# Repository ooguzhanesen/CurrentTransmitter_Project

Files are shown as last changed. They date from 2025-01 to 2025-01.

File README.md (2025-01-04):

# CURRENT TRANSMITTER KARTI
## KART ÖZELLİKLERİ
- 3 ADET  4-20 mA analog çıkış
- STM32f103C8 mikrodenetleyici 
- RS485 Portu
- 7-28 volt güç girişi
- Aşırı votaj koruması
- Ters bağlantı koruması
- Akım limitleyici
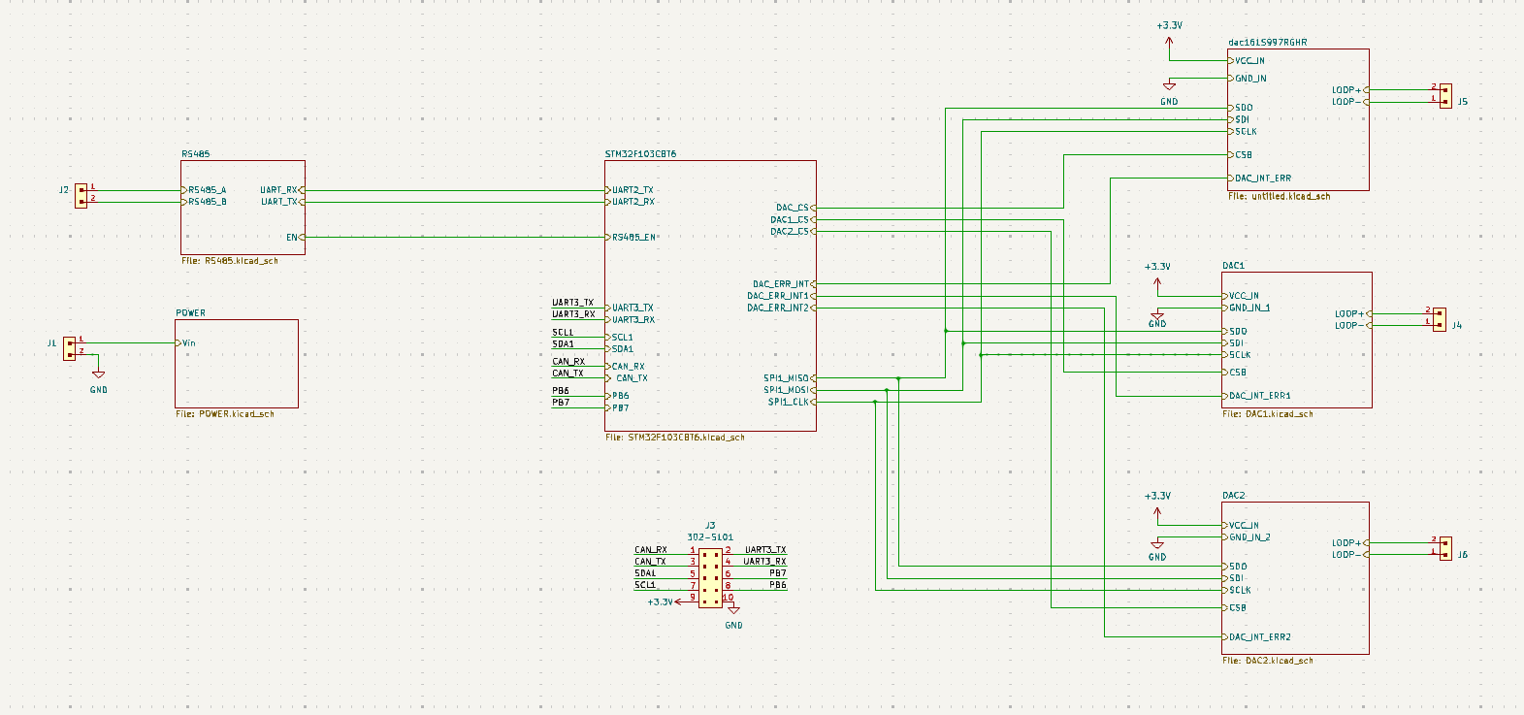
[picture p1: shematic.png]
semetik


## PCB TASARIM
CURRENT TRANSITTER kartı 4 katlı olacak şekilde KiCad üzerinden tasarlandı. 3 DAC'ın ve Mikrodenetleyicinin GND'leri birbirinden izole şekilde çizildi. PCB, DT-0505 kutusuna uygun olacak şekilde tasarlandı.
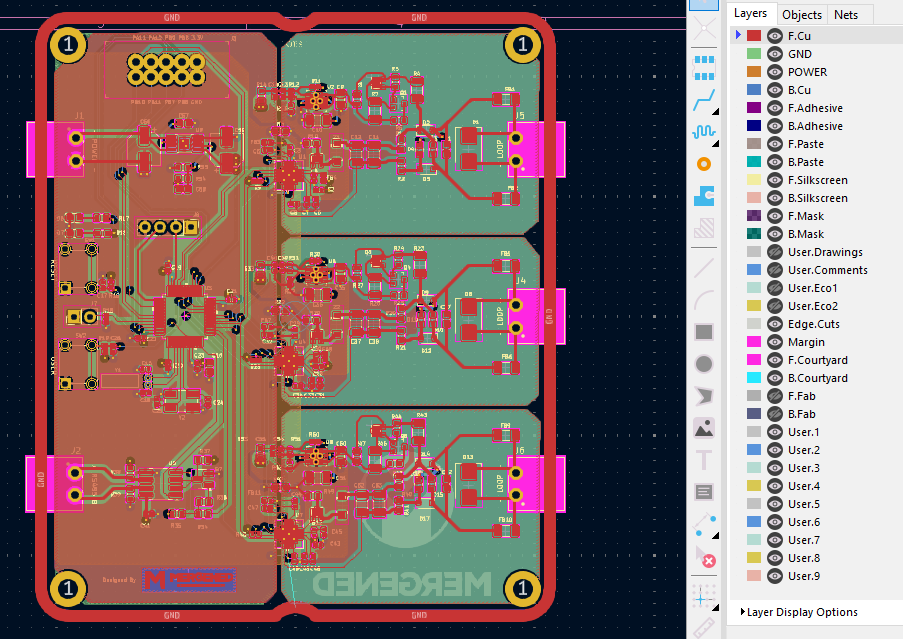
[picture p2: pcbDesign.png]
tasarım


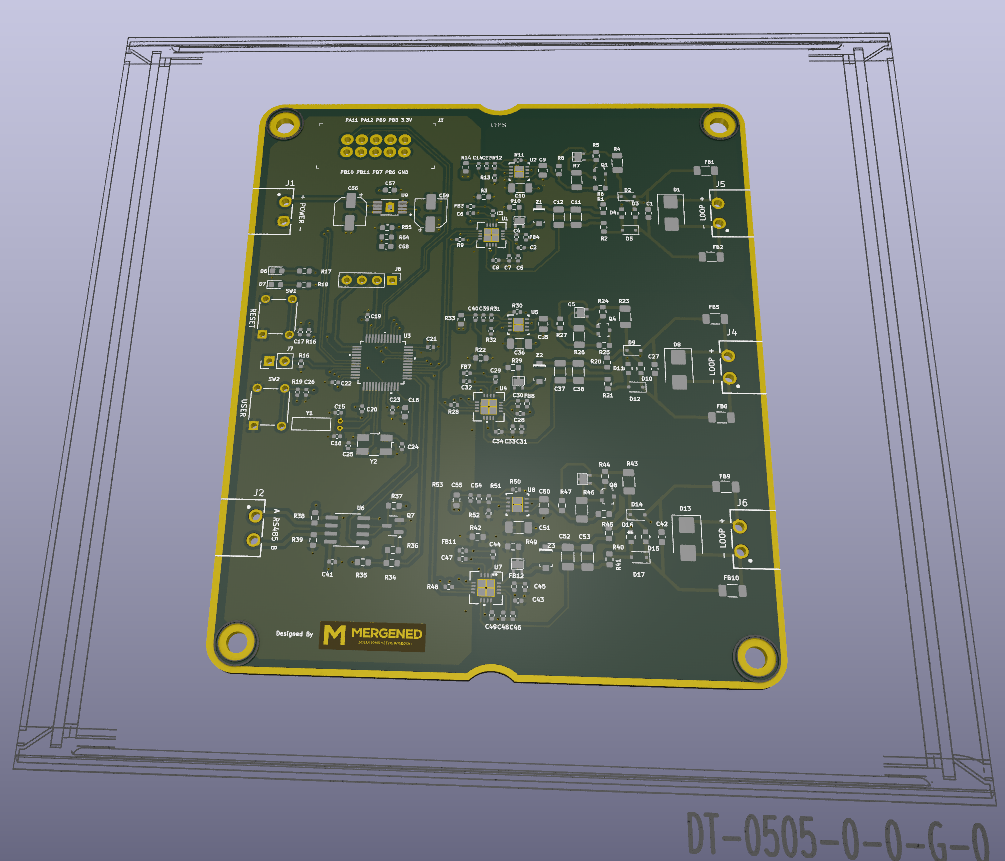
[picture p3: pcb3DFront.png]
tasarım 3d gorünüm

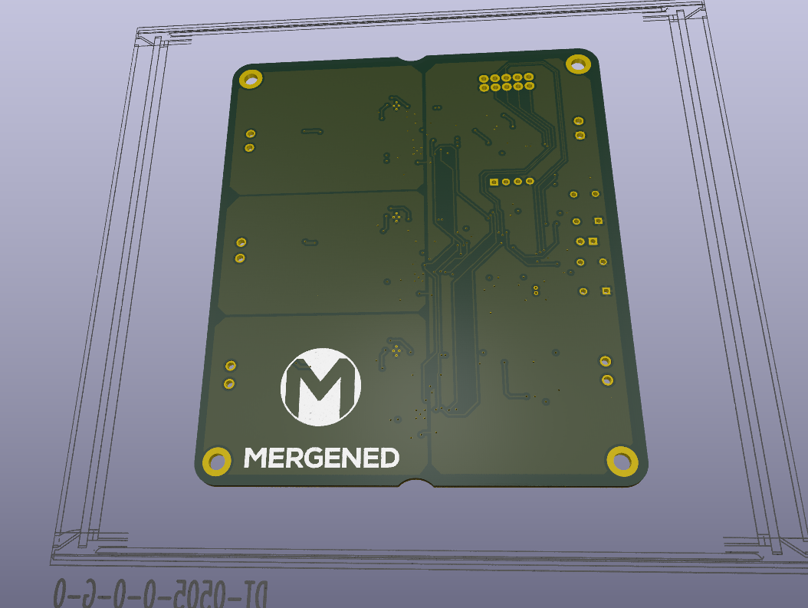
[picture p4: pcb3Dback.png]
Backside

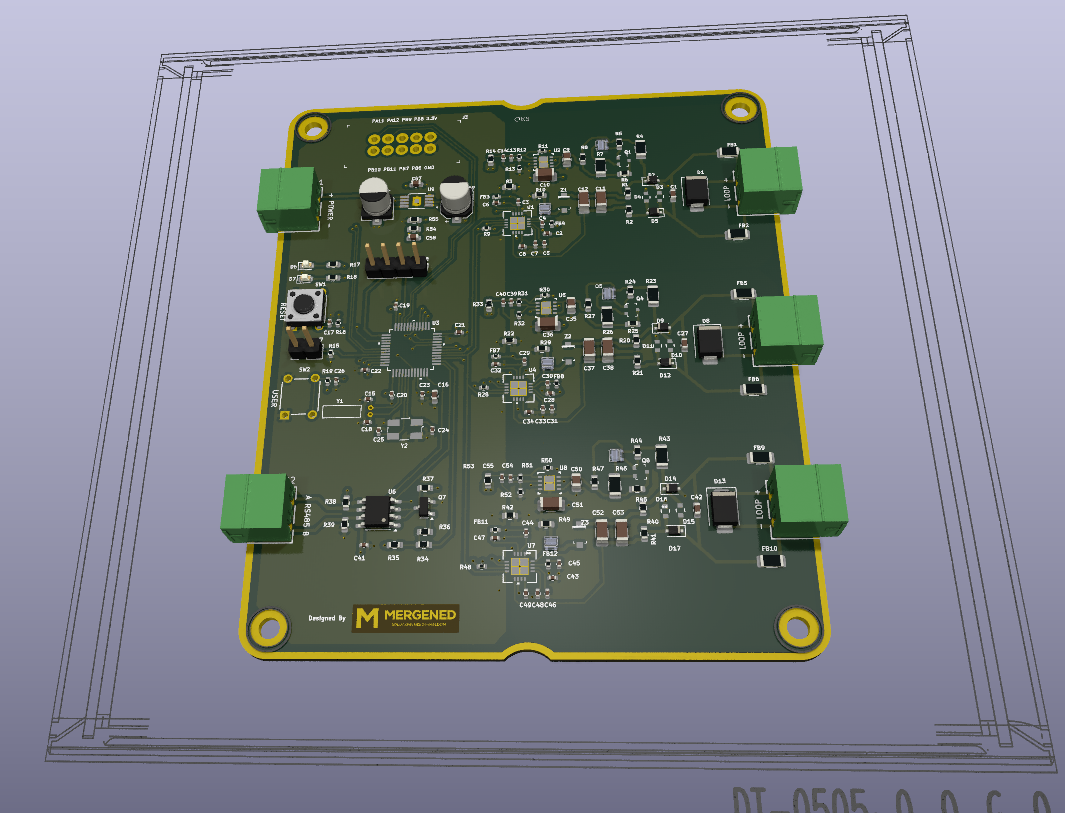
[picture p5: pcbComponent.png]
3d


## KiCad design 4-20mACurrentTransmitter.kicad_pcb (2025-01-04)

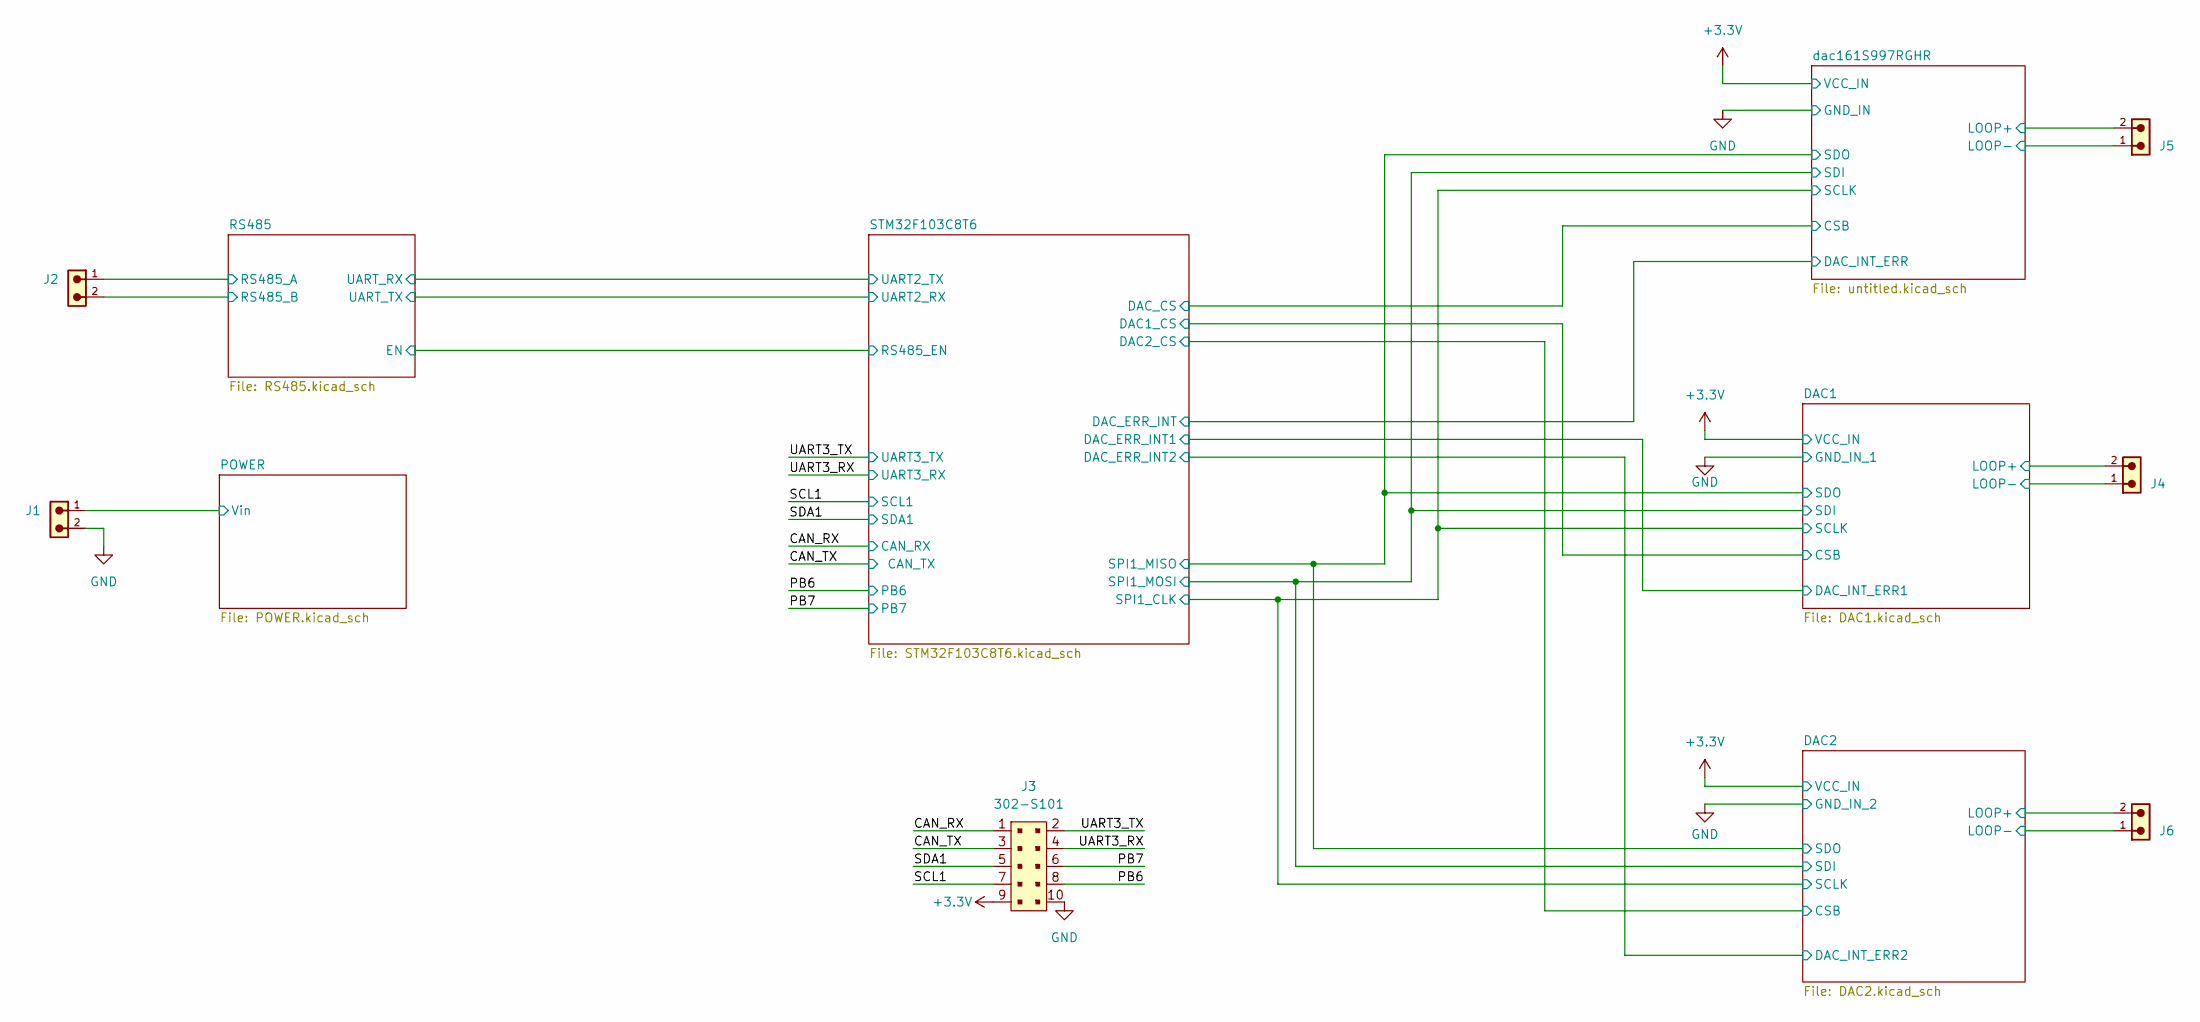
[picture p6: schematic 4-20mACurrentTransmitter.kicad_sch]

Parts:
J1, J2, J4, J5, J6: 691322310002; PART-NUMBER 691322310002; DigiKey 732-2088-ND
J3: 302-S101; PinHeader_2x5_P2.54mm_Drill1.2mm; MPN 302-S101; DigiKey ED1543-ND

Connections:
+3.3V: J3.9; also elsewhere on the board
/CAN_RX: J3.1; also elsewhere on the board
/CAN_TX: J3.3; also elsewhere on the board
/DAC1/LOOP+: J4.2; also elsewhere on the board
/DAC1/LOOP-: J4.1; also elsewhere on the board
/DAC2/LOOP+: J6.2; also elsewhere on the board
/DAC2/LOOP-: J6.1; also elsewhere on the board
/PB6: J3.8; also elsewhere on the board
/PB7: J3.6; also elsewhere on the board
/POWER/Vin: J1.1; also elsewhere on the board
/RS485/RS485_A: J2.1; also elsewhere on the board
/RS485/RS485_B: J2.2; also elsewhere on the board
/SCL1: J3.7; also elsewhere on the board
/SDA1: J3.5; also elsewhere on the board
/UART3_RX: J3.4; also elsewhere on the board
/UART3_TX: J3.2; also elsewhere on the board
/dac161S997RGHR/LOOP+: J5.2; also elsewhere on the board
/dac161S997RGHR/LOOP-: J5.1; also elsewhere on the board

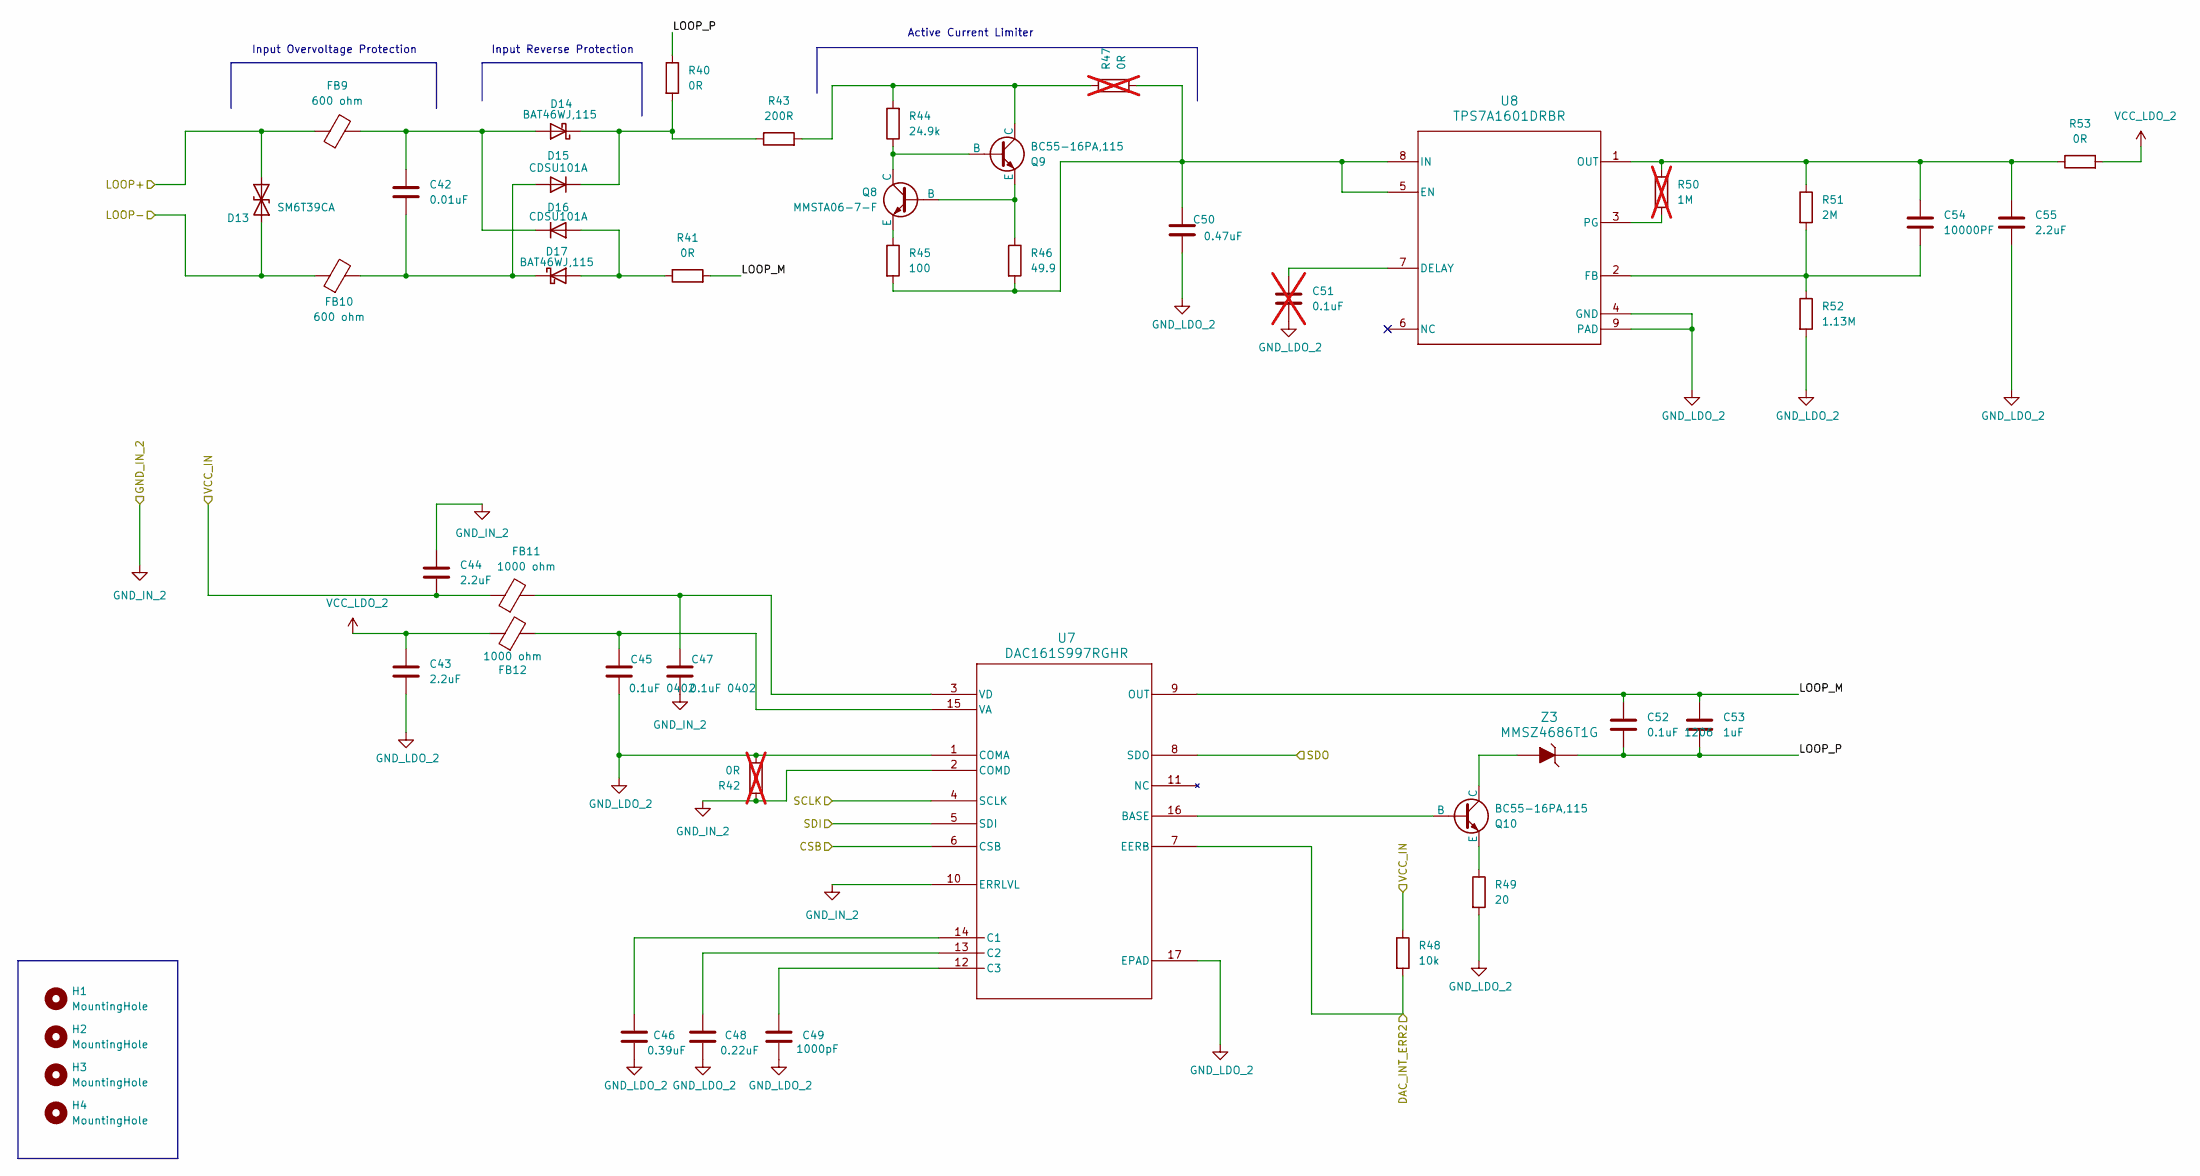
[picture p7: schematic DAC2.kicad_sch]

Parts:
C42: 0.01uF; C_0603_1608Metric; DIGIKEY 445-1304-2-ND
C43, C44, C55: 2.2uF; C_0402_1005Metric; DIGIKEY 445-9085-2-ND
C45, C47: 0.1uF 0402; C_0402_1005Metric; DIGIKEY 445-1266-2-ND
C46: 0.39uF; C_0402_1005Metric; DIGIKEY 490-8253-2-ND
C48: 0.22uF; C_0402_1005Metric; DIGIKEY 490-5407-2-ND
C49: 1000pF; C_0402_1005Metric; DIGIKEY 490-6285-2-ND
C50: 0.47uF; C_0805_2012Metric; DIGIKEY 490-3326-2-ND
C51: 0.1uF; C_1206_3216Metric; DIGIKEY 478-KGM31DR72A104JUTR-ND; not fitted
C52: 0.1uF 1206; C_1206_3216Metric; DIGIKEY 478-KGM31DR72A104JUTR-ND
C53: 1uF; C_1206_3216Metric; DIGIKEY 490-3909-2-ND
C54: 10000PF; C_0402_1005Metric; DIGIKEY 490-6296-2-ND
D13: SM6T39CA; D_SMB; DIGIKEY 497-6498-2-ND
D14, D17: BAT46WJ,115; D_SOD-323F; DIGIKEY 1727-4817-2-ND
D15, D16: CDSU101A; LED_CDSU101A; DIGIKEY 641-1002-2-ND
FB9, FB10: 600 ohm; R_1206_3216Metric; DIGIKEY 240-2405-2-ND
FB11, FB12: 1000 ohm; R_0402_1005Metric; DIGIKEY 490-3999-2-ND
H1, H2, H3, H4: MountingHole; MountingHole_3.2mm_M3_DIN965_Pad
Q8: MMSTA06-7-F; SOT-323; DIGIKEY MMSTA06-FDITR-ND
Q9, Q10: BC55-16PA,115; 3-HUSON(2X2); DIGIKEY 1727-2344-2-ND
R40, R41, R53: 0R; R_0603_1608Metric; DIGIKEY 541-0.0GTR-ND
R42, R47: 0R; R_0603_1608Metric; DIGIKEY 541-0.0GTR-ND; not fitted
R43: 200R; R_1206_3216Metric; DIGIKEY 541-200FTR-ND
R44: 24.9k; R_0603_1608Metric; DIGIKEY 541-4028-2-ND
R45: 100; R_0603_1608Metric; DIGIKEY 541-100STR-ND
R46: 49.9; R_1206_3216Metric; DIGIKEY 541-4185-2-ND
R48: 10k; R_0402_1005Metric; DIGIKEY 311-10KJRTR-ND
R49: 20; R_0603_1608Metric; DIGIKEY 541-20.0HTR-ND
R50: 1M; R_0402_1005Metric; DIGIKEY 541-4119-2-ND; not fitted
R51: 2M; R_0402_1005Metric; DIGIKEY 541-4066-2-ND
R52: 1.13M; R_0402_1005Metric; DIGIKEY 541-1.13MLTR-ND
U7: DAC161S997RGHR; RGH16_TEX; DIGIKEY 296-40022-2-ND
U8: TPS7A1601DRBR; DRB0008B; DIGIKEY 96-40969-2-ND
Z3: MMSZ4686T1G; SOD-123; DIGIKEY MMSZ4686T1GOSTR-ND

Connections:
+3.3V: C44.2, FB11.1, R48.1; also elsewhere on the board
/DAC1/SCLK: U7.4 (SCLK); also elsewhere on the board
/DAC1/SDI: U7.5 (SDI); also elsewhere on the board
/DAC1/SDO: U7.8 (SDO); also elsewhere on the board
/DAC2/CSB: U7.6 (CSB); also elsewhere on the board
/DAC2/DAC_INT_ERR2: R48.2, U7.7 (EERB); also elsewhere on the board
/DAC2/LOOP+: D13.1 (A1), FB9.1; also elsewhere on the board
/DAC2/LOOP-: D13.2 (A2), FB10.1; also elsewhere on the board
/DAC2/LOOP_M: C52.1, C53.1, R41.2, U7.9 (OUT)
/DAC2/LOOP_P: C52.2, C53.2, R40.1, Z3.K
GND_LDO_2: C43.2, C45.2, C46.2, C48.2, C49.2, C50.2, C51.2, C55.2, R42.2, R49.2, R52.2, U7.1 (COMA), U7.17 (EPAD), U8.4 (GND), U8.9 (PAD)
unnamed: C42.1, D14.2 (A), D16.1 (K), FB9.2
unnamed: D14.1 (K), D15.1 (K), R40.2, R43.1
unnamed: C42.2, D15.2 (A), D17.1 (K), FB10.2
unnamed: D16.2 (A), D17.2 (A), R41.1
unnamed: Q8.2 (B), Q9.3 (E), R46.1
unnamed: Q8.1 (C), Q9.2 (B), R44.1
unnamed: Q8.3 (E), R45.1
unnamed: Q9.1 (C), R43.2, R44.2, R47.1
unnamed: Q10.2 (B), U7.16 (BASE)
unnamed: Q10.1 (C), Z3.A
unnamed: Q10.3 (E), R49.1
unnamed: C46.1, U7.14 (C1)
unnamed: C48.1, U7.13 (C2)
unnamed: C49.1, U7.12 (C3)
unnamed: C45.1, FB12.2, U7.15 (VA)
unnamed: C47.1, FB11.2, U7.3 (VD)
unnamed: C51.1, U8.7 (DELAY)
unnamed: C50.1, R45.2, R46.2, R47.2, U8.5 (EN), U8.8 (IN)
unnamed: C54.2, R51.2, R52.1, U8.2 (FB)
unnamed: C54.1, C55.1, R50.1, R51.1, R53.1, U8.1 (OUT)
unnamed: R50.2, U8.3 (PG)
VCC_LDO_2: C43.1, FB12.1, R53.2

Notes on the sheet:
Input Overvoltage Protection
Input Reverse Protection
Active Current Limiter

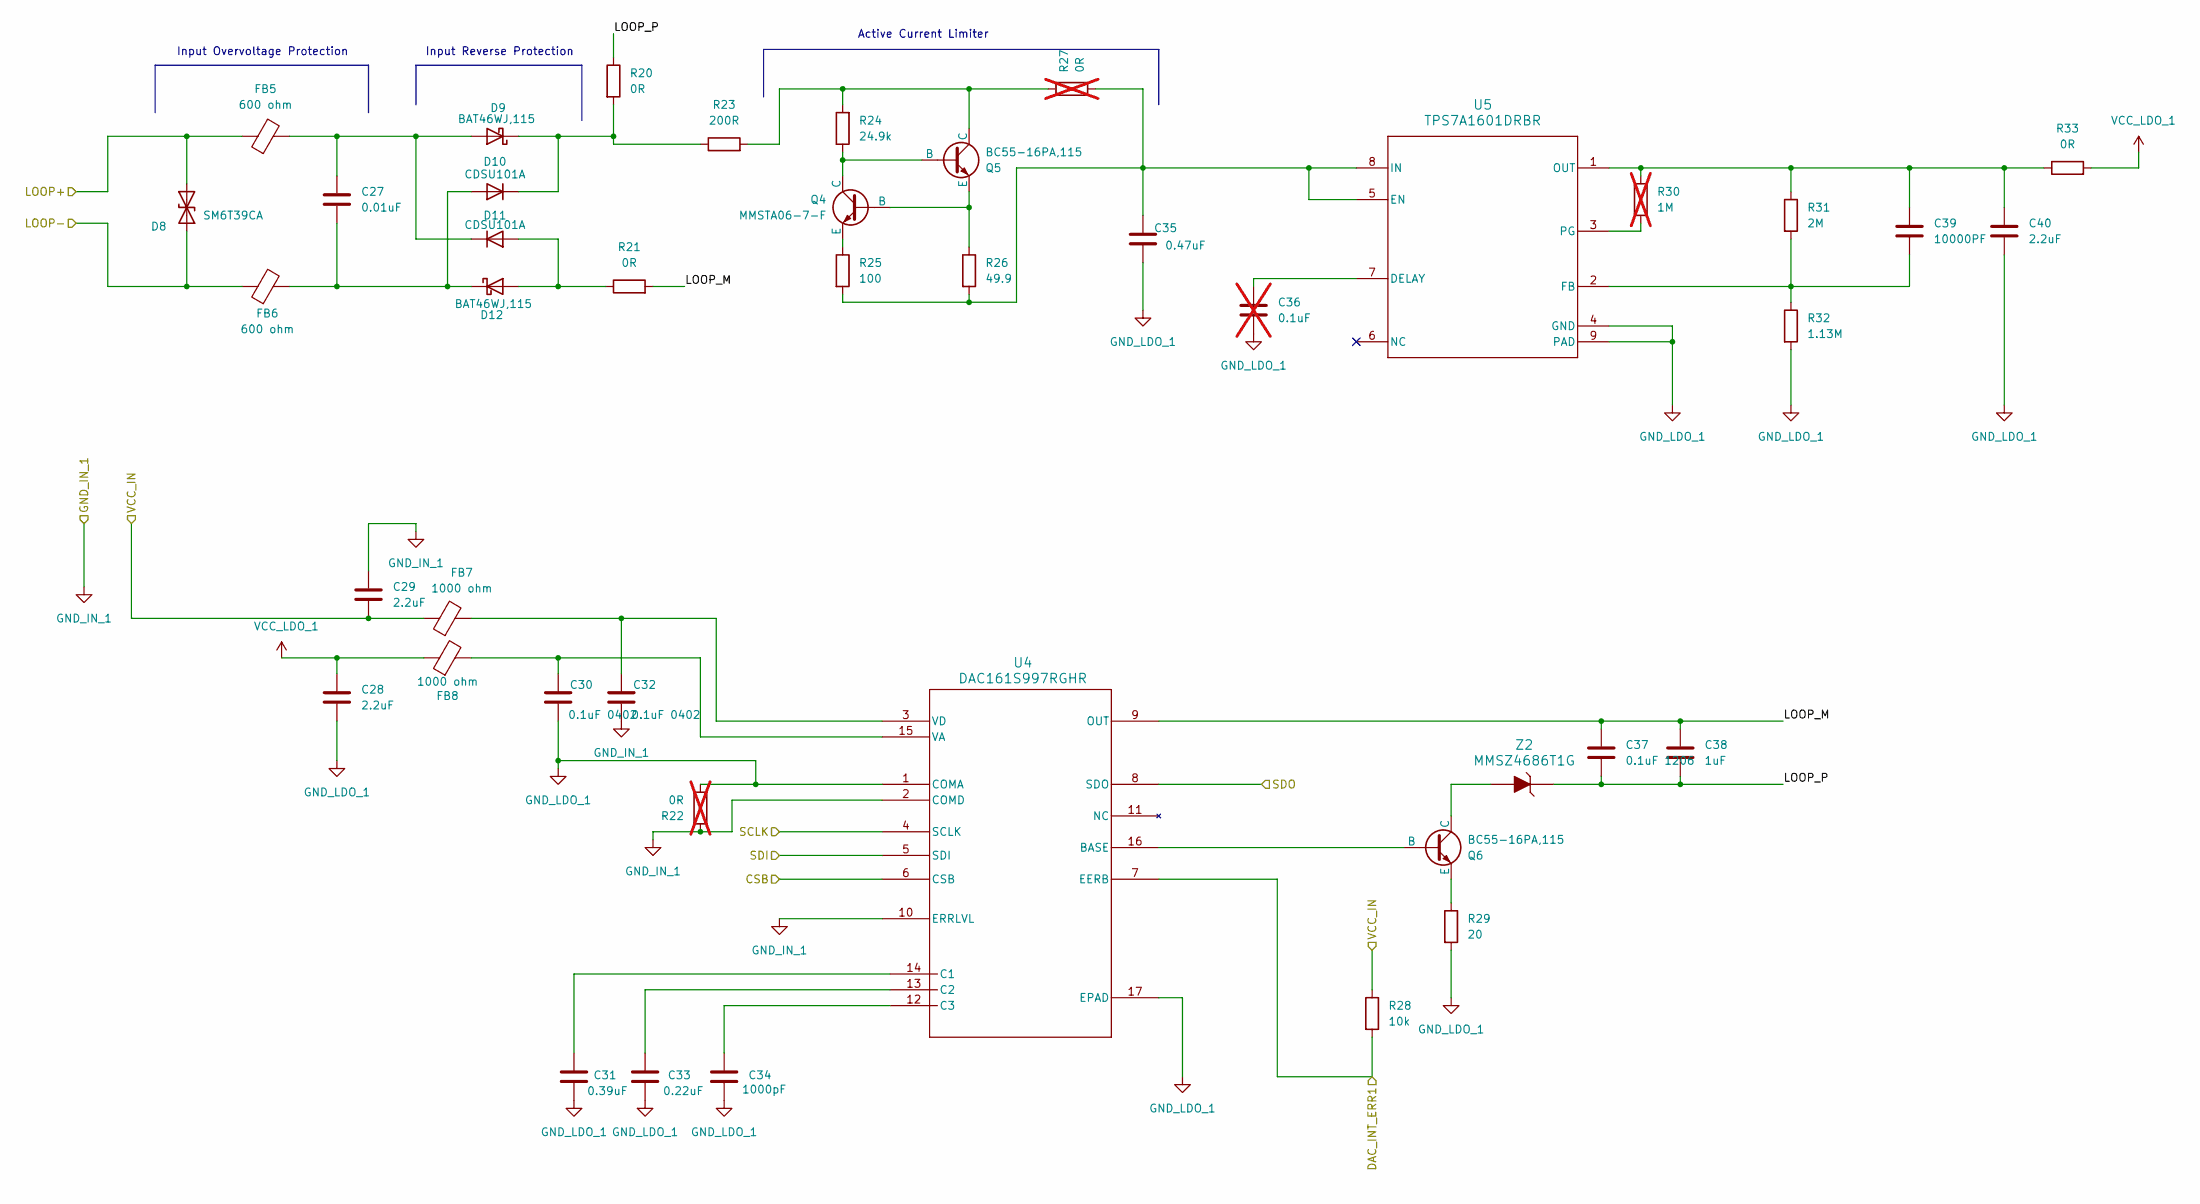
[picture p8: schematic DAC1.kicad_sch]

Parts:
C27: 0.01uF; C_0603_1608Metric; DIGIKEY 445-1304-2-ND
C28, C29, C40: 2.2uF; C_0402_1005Metric; DIGIKEY 445-9085-2-ND
C30, C32: 0.1uF 0402; C_0402_1005Metric; DIGIKEY 445-1266-2-ND
C31: 0.39uF; C_0402_1005Metric; DIGIKEY 490-8253-2-ND
C33: 0.22uF; C_0402_1005Metric; DIGIKEY 490-5407-2-ND
C34: 1000pF; C_0402_1005Metric; DIGIKEY 490-6285-2-ND
C35: 0.47uF; C_0805_2012Metric; DIGIKEY 490-3326-2-ND
C36: 0.1uF; C_1206_3216Metric; DIGIKEY 478-KGM31DR72A104JUTR-ND; not fitted
C37: 0.1uF 1206; C_1206_3216Metric; DIGIKEY 478-KGM31DR72A104JUTR-ND
C38: 1uF; C_1206_3216Metric; DIGIKEY 490-3909-2-ND
C39: 10000PF; C_0402_1005Metric; DIGIKEY 490-6296-2-ND
D8: SM6T39CA; D_SMB; DIGIKEY 497-6498-2-ND
D9, D12: BAT46WJ,115; D_SOD-323F; DIGIKEY 1727-4817-2-ND
D10, D11: CDSU101A; LED_CDSU101A; DIGIKEY 641-1002-2-ND
FB5, FB6: 600 ohm; R_1206_3216Metric; DIGIKEY 240-2405-2-ND
FB7, FB8: 1000 ohm; R_0402_1005Metric; DIGIKEY 490-3999-2-ND
Q4: MMSTA06-7-F; SOT-323; DIGIKEY MMSTA06-FDITR-ND
Q5, Q6: BC55-16PA,115; 3-HUSON(2X2); DIGIKEY 1727-2344-2-ND
R20, R21, R33: 0R; R_0603_1608Metric; DIGIKEY 541-0.0GTR-ND
R22, R27: 0R; R_0603_1608Metric; DIGIKEY 541-0.0GTR-ND; not fitted
R23: 200R; R_1206_3216Metric; DIGIKEY 541-200FTR-ND
R24: 24.9k; R_0603_1608Metric; DIGIKEY 541-4028-2-ND
R25: 100; R_0603_1608Metric; DIGIKEY 541-100STR-ND
R26: 49.9; R_1206_3216Metric; DIGIKEY 541-4185-2-ND
R28: 10k; R_0402_1005Metric; DIGIKEY 311-10KJRTR-ND
R29: 20; R_0603_1608Metric; DIGIKEY 541-20.0HTR-ND
R30: 1M; R_0402_1005Metric; DIGIKEY 541-4119-2-ND; not fitted
R31: 2M; R_0402_1005Metric; DIGIKEY 541-4066-2-ND
R32: 1.13M; R_0402_1005Metric; DIGIKEY 541-1.13MLTR-ND
U4: DAC161S997RGHR; RGH16_TEX; DIGIKEY 296-40022-2-ND
U5: TPS7A1601DRBR; DRB0008B; DIGIKEY 96-40969-2-ND
Z2: MMSZ4686T1G; SOD-123; DIGIKEY MMSZ4686T1GOSTR-ND

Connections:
+3.3V: C29.2, FB7.1, R28.1; also elsewhere on the board
/DAC1/CSB: U4.6 (CSB); also elsewhere on the board
/DAC1/DAC_INT_ERR1: R28.2, U4.7 (EERB); also elsewhere on the board
/DAC1/LOOP+: D8.1 (A1), FB5.1; also elsewhere on the board
/DAC1/LOOP-: D8.2 (A2), FB6.1; also elsewhere on the board
/DAC1/LOOP_M: C37.1, C38.1, R21.2, U4.9 (OUT)
/DAC1/LOOP_P: C37.2, C38.2, R20.1, Z2.K
/DAC1/SCLK: U4.4 (SCLK); also elsewhere on the board
/DAC1/SDI: U4.5 (SDI); also elsewhere on the board
/DAC1/SDO: U4.8 (SDO); also elsewhere on the board
GND_LDO_1: C28.2, C30.2, C31.2, C33.2, C34.2, C35.2, C36.2, C40.2, R22.2, R29.2, R32.2, U4.1 (COMA), U4.17 (EPAD), U5.4 (GND), U5.9 (PAD)
unnamed: C27.2, D10.2 (A), D12.1 (K), FB6.2
unnamed: D9.1 (K), D10.1 (K), R20.2, R23.1
unnamed: D11.2 (A), D12.2 (A), R21.1
unnamed: C27.1, D9.2 (A), D11.1 (K), FB5.2
unnamed: Q4.2 (B), Q5.3 (E), R26.1
unnamed: Q4.1 (C), Q5.2 (B), R24.1
unnamed: Q4.3 (E), R25.1
unnamed: Q5.1 (C), R23.2, R24.2, R27.1
unnamed: Q6.2 (B), U4.16 (BASE)
unnamed: Q6.1 (C), Z2.A
unnamed: Q6.3 (E), R29.1
unnamed: C31.1, U4.14 (C1)
unnamed: C33.1, U4.13 (C2)
unnamed: C34.1, U4.12 (C3)
unnamed: C30.1, FB8.2, U4.15 (VA)
unnamed: C32.1, FB7.2, U4.3 (VD)
unnamed: C36.1, U5.7 (DELAY)
unnamed: C35.1, R25.2, R26.2, R27.2, U5.5 (EN), U5.8 (IN)
unnamed: C39.2, R31.2, R32.1, U5.2 (FB)
unnamed: C39.1, C40.1, R30.1, R31.1, R33.1, U5.1 (OUT)
unnamed: R30.2, U5.3 (PG)
VCC_LDO_1: C28.1, FB8.1, R33.2

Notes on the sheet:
Input Overvoltage Protection
Input Reverse Protection
Active Current Limiter

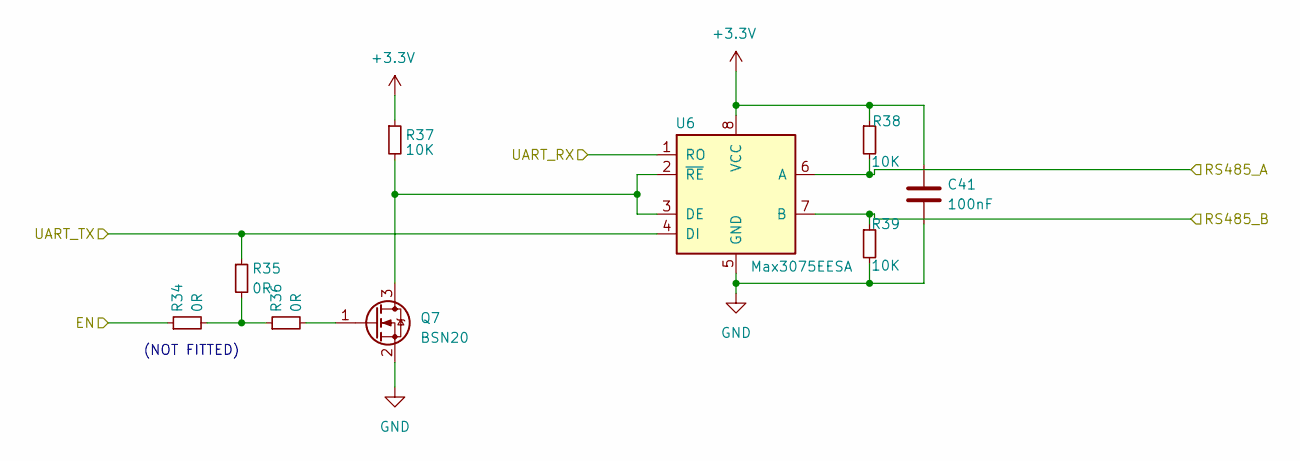
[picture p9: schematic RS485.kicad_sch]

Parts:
C41: 100nF; C_0402_1005Metric; DIGIKEY 3372-0402B104K500HITR-ND
Q7: BSN20; SOT-23; DIGIKEY BSN20-7DITR-ND
R34, R35, R36: 0R; R_0603_1608Metric; DIGIKEY 541-0.0GTR-ND
R37, R38, R39: 10K; R_0603_1608Metric; DIGIKEY 311-10.0KHRTR-ND
U6: Max3075EESA; SOIC-8_3.9x4.9mm_P1.27mm; DIGIKEY MAX3075EESA+-ND

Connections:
+3.3V: C41.1, R37.1, R38.1, U6.8 (VCC); also elsewhere on the board
/RS485/EN: R34.1; also elsewhere on the board
/RS485/RS485_A: R38.2, U6.6 (A); also elsewhere on the board
/RS485/RS485_B: R39.1, U6.7 (B); also elsewhere on the board
/RS485/UART_RX: U6.1 (RO); also elsewhere on the board
/RS485/UART_TX: R35.1, U6.4 (DI); also elsewhere on the board
unnamed: Q7.3 (D), R37.2, U6.2 (~RE), U6.3 (DE)
unnamed: Q7.1 (G), R36.2
unnamed: R34.2, R35.2, R36.1

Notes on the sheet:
(NOT FITTED)

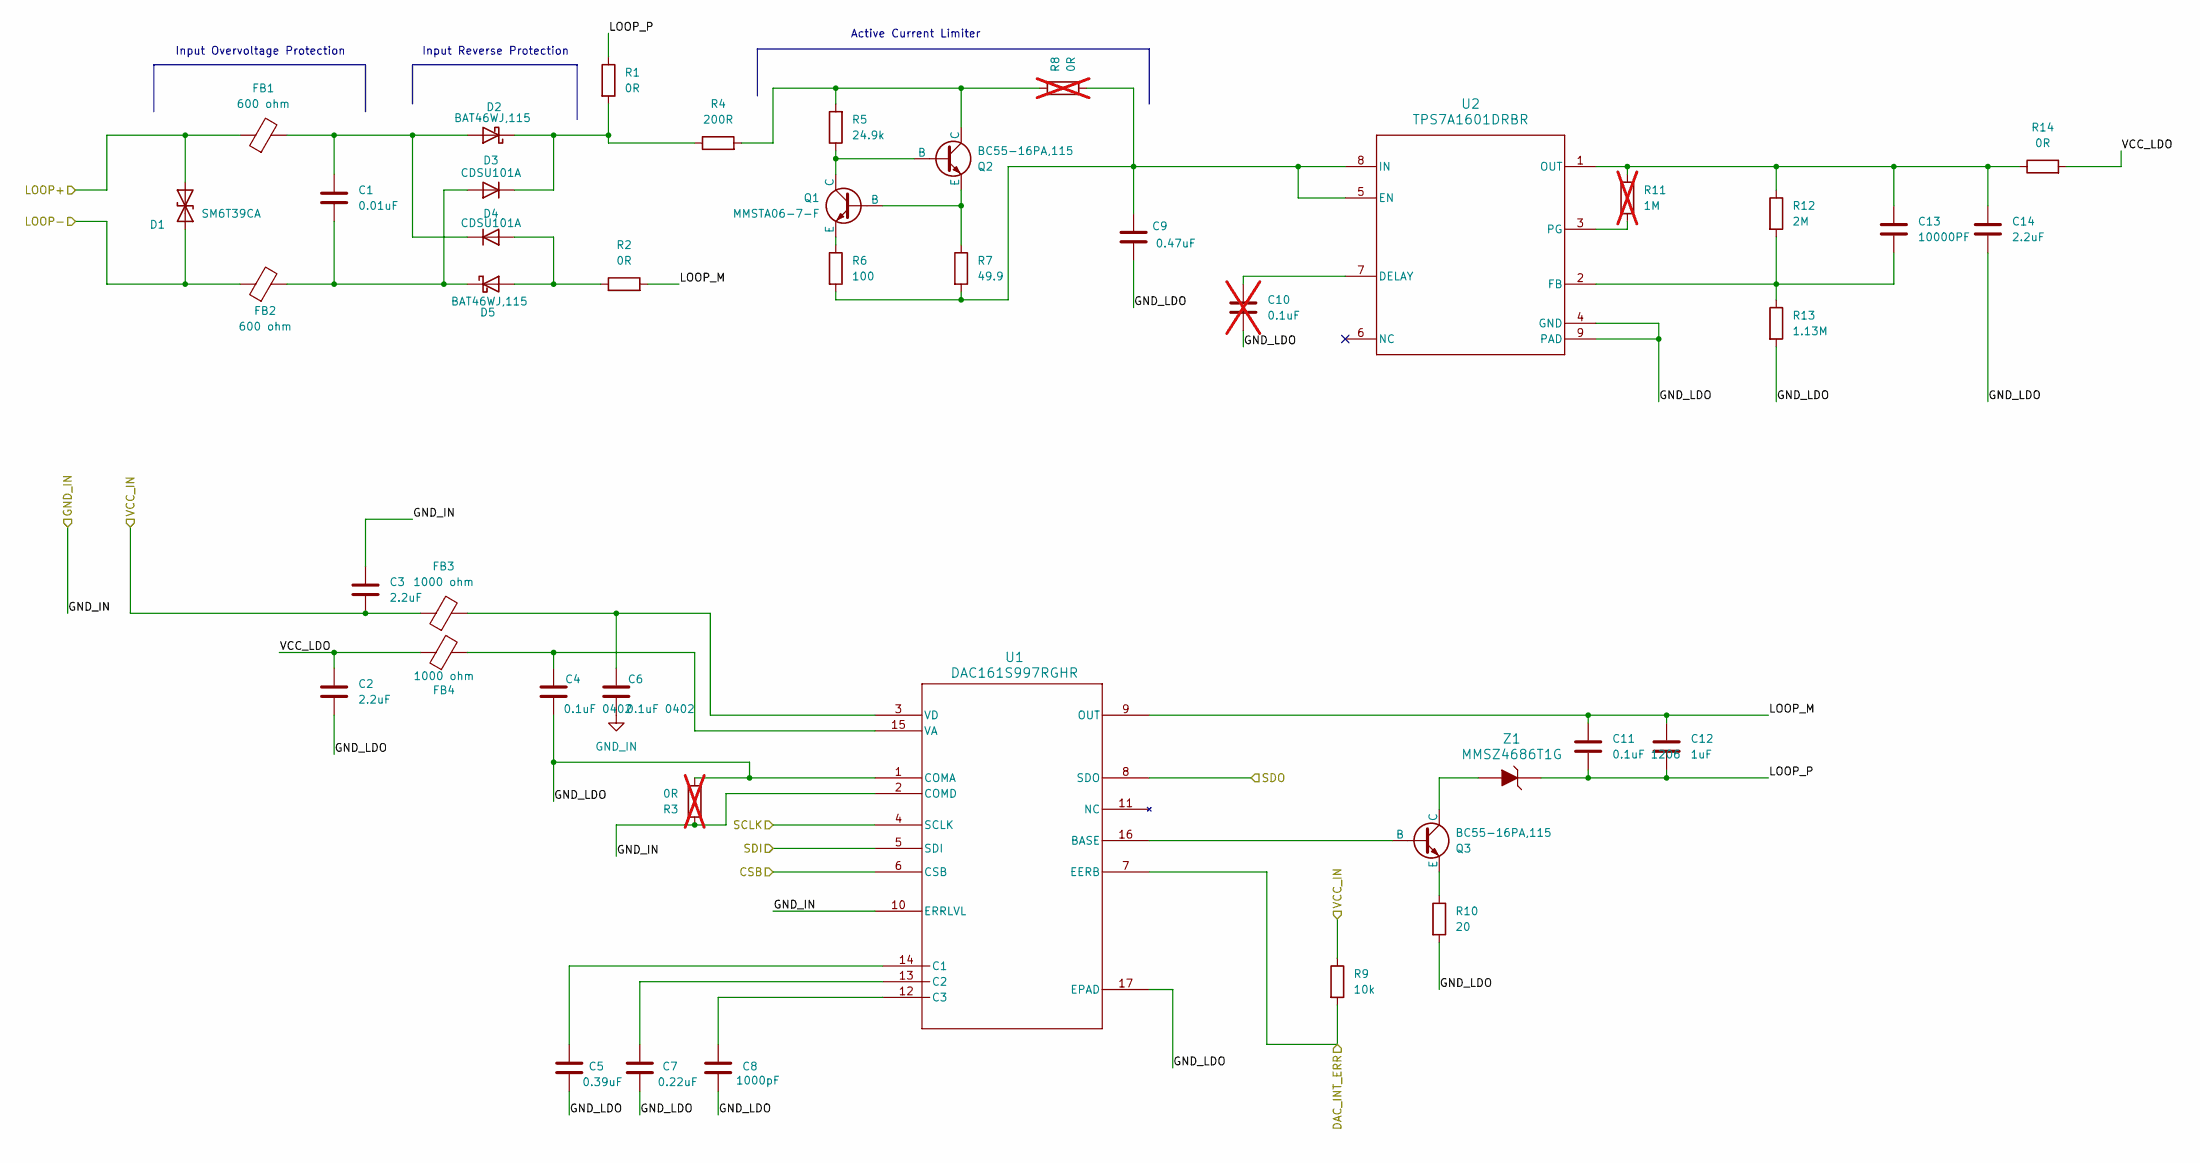
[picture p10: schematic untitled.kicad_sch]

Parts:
C1: 0.01uF; C_0603_1608Metric; DIGIKEY 445-1304-2-ND
C2, C3, C14: 2.2uF; C_0402_1005Metric; DIGIKEY 445-9085-2-ND
C4, C6: 0.1uF 0402; C_0402_1005Metric; DIGIKEY 445-1266-2-ND
C5: 0.39uF; C_0402_1005Metric; DIGIKEY 490-8253-2-ND
C7: 0.22uF; C_0402_1005Metric; DIGIKEY 490-5407-2-ND
C8: 1000pF; C_0402_1005Metric; DIGIKEY 490-6285-2-ND
C9: 0.47uF; C_0805_2012Metric; DIGIKEY 490-3326-2-ND
C10: 0.1uF; C_1206_3216Metric; DIGIKEY 478-KGM31DR72A104JUTR-ND; not fitted
C11: 0.1uF 1206; C_1206_3216Metric; DIGIKEY 478-KGM31DR72A104JUTR-ND
C12: 1uF; C_1206_3216Metric; DIGIKEY 490-3909-2-ND
C13: 10000PF; C_0402_1005Metric; DIGIKEY 490-6296-2-ND
D1: SM6T39CA; D_SMB; DIGIKEY 497-6498-2-ND
D2, D5: BAT46WJ,115; D_SOD-323F; DIGIKEY 1727-4817-2-ND
D3, D4: CDSU101A; LED_CDSU101A; DIGIKEY 641-1002-2-ND
FB1, FB2: 600 ohm; R_1206_3216Metric; DIGIKEY 240-2405-2-ND
FB3, FB4: 1000 ohm; R_0402_1005Metric; DIGIKEY 490-3999-2-ND
Q1: MMSTA06-7-F; SOT-323; DIGIKEY MMSTA06-FDITR-ND
Q2, Q3: BC55-16PA,115; 3-HUSON(2X2); DIGIKEY 1727-2344-2-ND
R1, R2, R14: 0R; R_0603_1608Metric; DIGIKEY 541-0.0GTR-ND
R3, R8: 0R; R_0603_1608Metric; DIGIKEY 541-0.0GTR-ND; not fitted
R4: 200R; R_1206_3216Metric; DIGIKEY 541-200FTR-ND
R5: 24.9k; R_0603_1608Metric; DIGIKEY 541-4028-2-ND
R6: 100; R_0603_1608Metric; DIGIKEY 541-100STR-ND
R7: 49.9; R_1206_3216Metric; DIGIKEY 541-4185-2-ND
R9: 10k; R_0402_1005Metric; DIGIKEY 311-10KJRTR-ND
R10: 20; R_0603_1608Metric; DIGIKEY 541-20.0HTR-ND
R11: 1M; R_0402_1005Metric; DIGIKEY 541-4119-2-ND; not fitted
R12: 2M; R_0402_1005Metric; DIGIKEY 541-4066-2-ND
R13: 1.13M; R_0402_1005Metric; DIGIKEY 541-1.13MLTR-ND
U1: DAC161S997RGHR; RGH16_TEX; DIGIKEY 296-40022-2-ND
U2: TPS7A1601DRBR; DRB0008B; DIGIKEY 96-40969-2-ND
Z1: MMSZ4686T1G; SOD-123; DIGIKEY MMSZ4686T1GOSTR-ND

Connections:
+3.3V: C3.2, FB3.1, R9.1; also elsewhere on the board
/DAC1/SCLK: U1.4 (SCLK); also elsewhere on the board
/DAC1/SDI: U1.5 (SDI); also elsewhere on the board
/DAC1/SDO: U1.8 (SDO); also elsewhere on the board
/STM32F103C8T6/DAC_CS: U1.6 (CSB); also elsewhere on the board
/STM32F103C8T6/DAC_ERR_INT: R9.2, U1.7 (EERB); also elsewhere on the board
/dac161S997RGHR/GND_LDO: C2.2, C4.2, C5.2, C7.2, C8.2, C9.2, C10.2, C14.2, R3.2, R10.2, R13.2, U1.1 (COMA), U1.17 (EPAD), U2.4 (GND), U2.9 (PAD)
/dac161S997RGHR/LOOP+: D1.1 (A1), FB1.1; also elsewhere on the board
/dac161S997RGHR/LOOP-: D1.2 (A2), FB2.1; also elsewhere on the board
/dac161S997RGHR/LOOP_M: C11.1, C12.1, R2.2, U1.9 (OUT)
/dac161S997RGHR/LOOP_P: C11.2, C12.2, R1.1, Z1.K
/dac161S997RGHR/VCC_LDO: C2.1, FB4.1, R14.2
unnamed: C1.1, D2.2 (A), D4.1 (K), FB1.2
unnamed: D2.1 (K), D3.1 (K), R1.2, R4.1
unnamed: C1.2, D3.2 (A), D5.1 (K), FB2.2
unnamed: D4.2 (A), D5.2 (A), R2.1
unnamed: Q1.2 (B), Q2.3 (E), R7.1
unnamed: Q1.1 (C), Q2.2 (B), R5.1
unnamed: Q1.3 (E), R6.1
unnamed: Q2.1 (C), R4.2, R5.2, R8.1
unnamed: Q3.2 (B), U1.16 (BASE)
unnamed: Q3.1 (C), Z1.A
unnamed: Q3.3 (E), R10.1
unnamed: C5.1, U1.14 (C1)
unnamed: C7.1, U1.13 (C2)
unnamed: C8.1, U1.12 (C3)
unnamed: C4.1, FB4.2, U1.15 (VA)
unnamed: C6.1, FB3.2, U1.3 (VD)
unnamed: C10.1, U2.7 (DELAY)
unnamed: C9.1, R6.2, R7.2, R8.2, U2.5 (EN), U2.8 (IN)
unnamed: C13.2, R12.2, R13.1, U2.2 (FB)
unnamed: C13.1, C14.1, R11.1, R12.1, R14.1, U2.1 (OUT)
unnamed: R11.2, U2.3 (PG)

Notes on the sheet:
Active Current Limiter
Input Overvoltage Protection
Input Reverse Protection

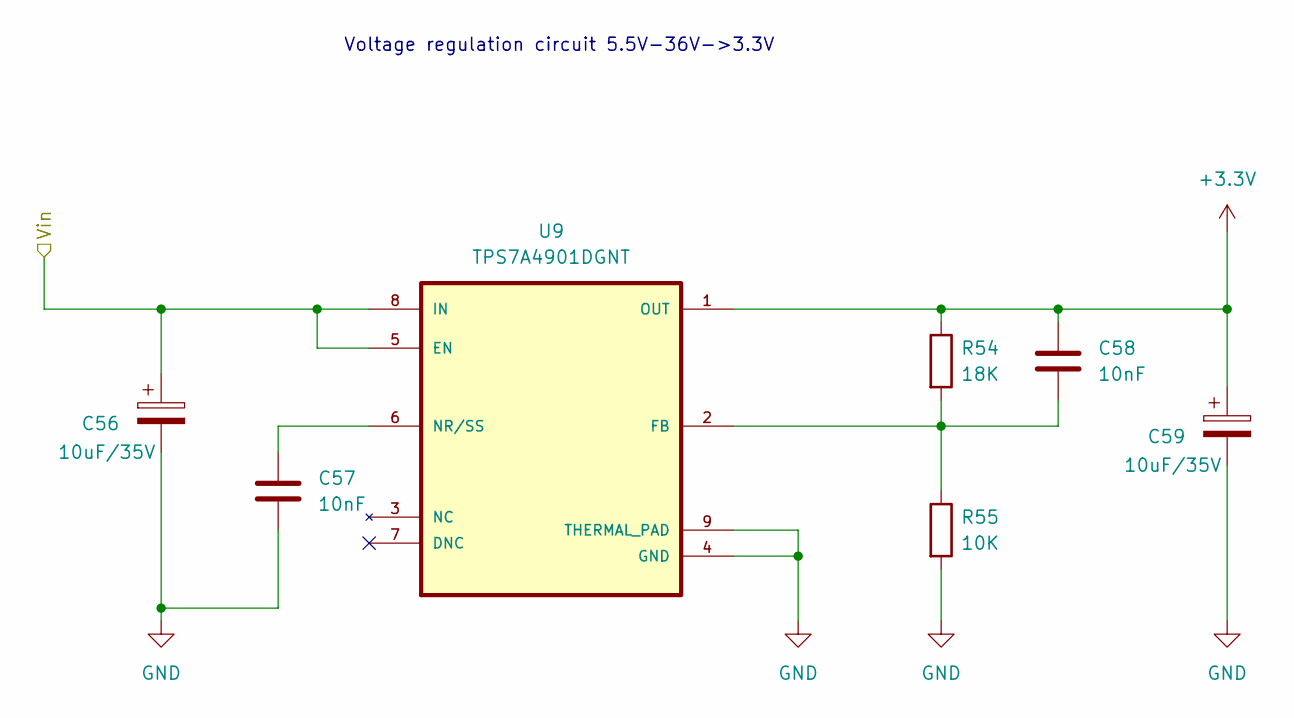
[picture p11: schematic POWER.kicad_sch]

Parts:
C56, C59: 10uF/35V; CP_Elec_5x5.4; DIGIKEY 732-8295-2-ND
C57, C58: 10nF; C_0603_1608Metric; DIGIKEY 399-C0603C103K4RECTUTR-ND
R54: 18K; R_0603_1608Metric; DIGIKEY 11-18KGRTR-ND
R55: 10K; R_0603_1608Metric; DIGIKEY 311-10.0KHRTR-ND
U9: TPS7A4901DGNT; SOP65P490X110-9N; DIGIKEY TPS7A4901DGNT

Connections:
+3.3V: C58.1, C59.1, R54.1, U9.1 (OUT); also elsewhere on the board
/POWER/Vin: C56.1, U9.5 (EN), U9.8 (IN); also elsewhere on the board
unnamed: C58.2, R54.2, R55.1, U9.2 (FB)
unnamed: C57.1, U9.6 (NR/SS)

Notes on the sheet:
Voltage regulation circuit 5.5V-36V->3.3V

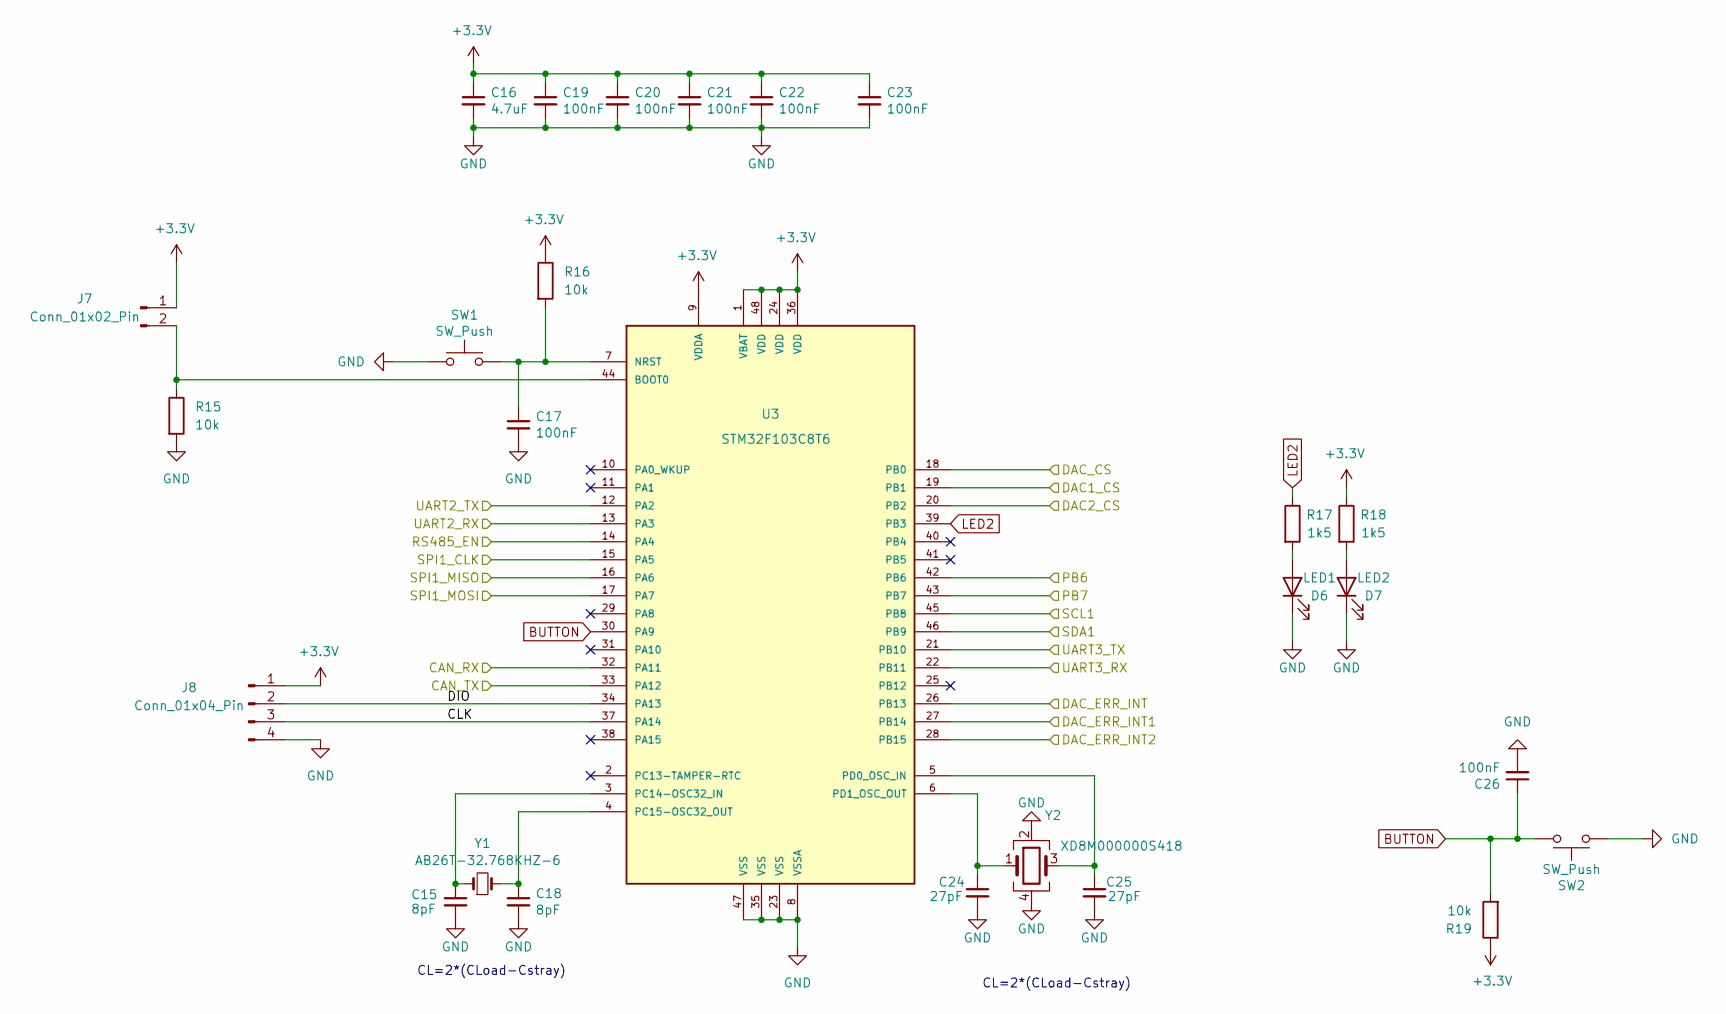
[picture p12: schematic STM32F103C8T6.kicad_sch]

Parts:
C15, C18: 8pF; C_0402_1005Metric; DIGIKEY 490-8230-2-ND
C16: 4.7uF; C_0603_1608Metric; DIGIKEY 3372-0603W475K100XDTR-ND
C17, C19, C20, C21, C22, C23, C26: 100nF; C_0402_1005Metric; DIGIKEY 3372-0402B104K500HITR-ND
C24, C25: 27pF; C_0402_1005Metric; DIGIKEY 2571-GMC04CG270G50NTTR-ND
D6: LED1; LED_0603_1608Metric; DIGIKEY 5859-YY0603YG-NN3S0-T2AR4TR-ND
D7: LED2; LED_0603_1608Metric; DIGIKEY 5859-YY0603RE-NN3S0-T2AR4TR-ND
J7: Conn_01x02_Pin; PinHeader_1x02_P2.54mm_Vertical; DIGIKEY 952-2262-ND
J8: Conn_01x04_Pin; PinHeader_1x04_P2.54mm_Vertical; DIGIKEY 732-5317-ND
R15, R16, R19: 10k; R_0402_1005Metric; DIGIKEY 311-10KJRTR-ND
R17, R18: 1k5; R_0603_1608Metric; DIGIKEY 311-1.5KGRTR-ND
SW1, SW2: SW_Push; pushbutton; DIGIKEY 1825910-6
U3: STM32F103C8T6; LQFP48_STM; DIGIKEY 497-6063-ND
Y1: AB26T-32.768KHZ-6; XTAL_AB26T-32.768KHZ-6; DIGIKEY 535-AB26T-32.768KHZ-6TR-ND
Y2: XD8M000000S418; Crystal_SMD_EuroQuartz_MJ-4Pin_5.0x3.2mm; DIGIKEY XD8M000000S418

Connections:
+3.3V: C16.1, C19.1, C20.1, C21.1, C22.1, C23.1, J7.1, J8.1, R16.1, R18.1, R19.1, U3.1 (VBAT), U3.9 (VDDA), U3.24 (VDD), U3.36 (VDD), U3.48 (VDD); also elsewhere on the board
/CAN_RX: U3.32 (PA11); also elsewhere on the board
/CAN_TX: U3.33 (PA12); also elsewhere on the board
/DAC1/CSB: U3.19 (PB1); also elsewhere on the board
/DAC1/DAC_INT_ERR1: U3.27 (PB14); also elsewhere on the board
/DAC1/SCLK: U3.15 (PA5); also elsewhere on the board
/DAC1/SDI: U3.17 (PA7); also elsewhere on the board
/DAC1/SDO: U3.16 (PA6); also elsewhere on the board
/DAC2/CSB: U3.20 (PB2); also elsewhere on the board
/DAC2/DAC_INT_ERR2: U3.28 (PB15); also elsewhere on the board
/PB6: U3.42 (PB6); also elsewhere on the board
/PB7: U3.43 (PB7); also elsewhere on the board
/RS485/EN: U3.14 (PA4); also elsewhere on the board
/RS485/UART_RX: U3.12 (PA2); also elsewhere on the board
/RS485/UART_TX: U3.13 (PA3); also elsewhere on the board
/SCL1: U3.45 (PB8); also elsewhere on the board
/SDA1: U3.46 (PB9); also elsewhere on the board
/STM32F103C8T6/CLK: J8.3, U3.37 (PA14)
/STM32F103C8T6/DAC_CS: U3.18 (PB0); also elsewhere on the board
/STM32F103C8T6/DAC_ERR_INT: U3.26 (PB13); also elsewhere on the board
/STM32F103C8T6/DIO: J8.2, U3.34 (PA13)
/UART3_RX: U3.22 (PB11); also elsewhere on the board
/UART3_TX: U3.21 (PB10); also elsewhere on the board
BUTTON: C26.1, R19.2, SW2.2, U3.30 (PA9)
LED2: R17.1, U3.39 (PB3)
unnamed: D6.2 (A), R17.2
unnamed: D7.2 (A), R18.2
unnamed: J7.2, R15.1, U3.44 (BOOT0)
unnamed: C17.1, R16.2, SW1.2, U3.7 (NRST)
unnamed: C15.1, U3.3 (PC14-OSC32_IN), Y1.1
unnamed: C18.1, U3.4 (PC15-OSC32_OUT), Y1.2
unnamed: C25.1, U3.5 (PD0_OSC_IN), Y2.3
unnamed: C24.1, U3.6 (PD1_OSC_OUT), Y2.1

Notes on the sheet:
CL=2*(CLoad-Cstray)

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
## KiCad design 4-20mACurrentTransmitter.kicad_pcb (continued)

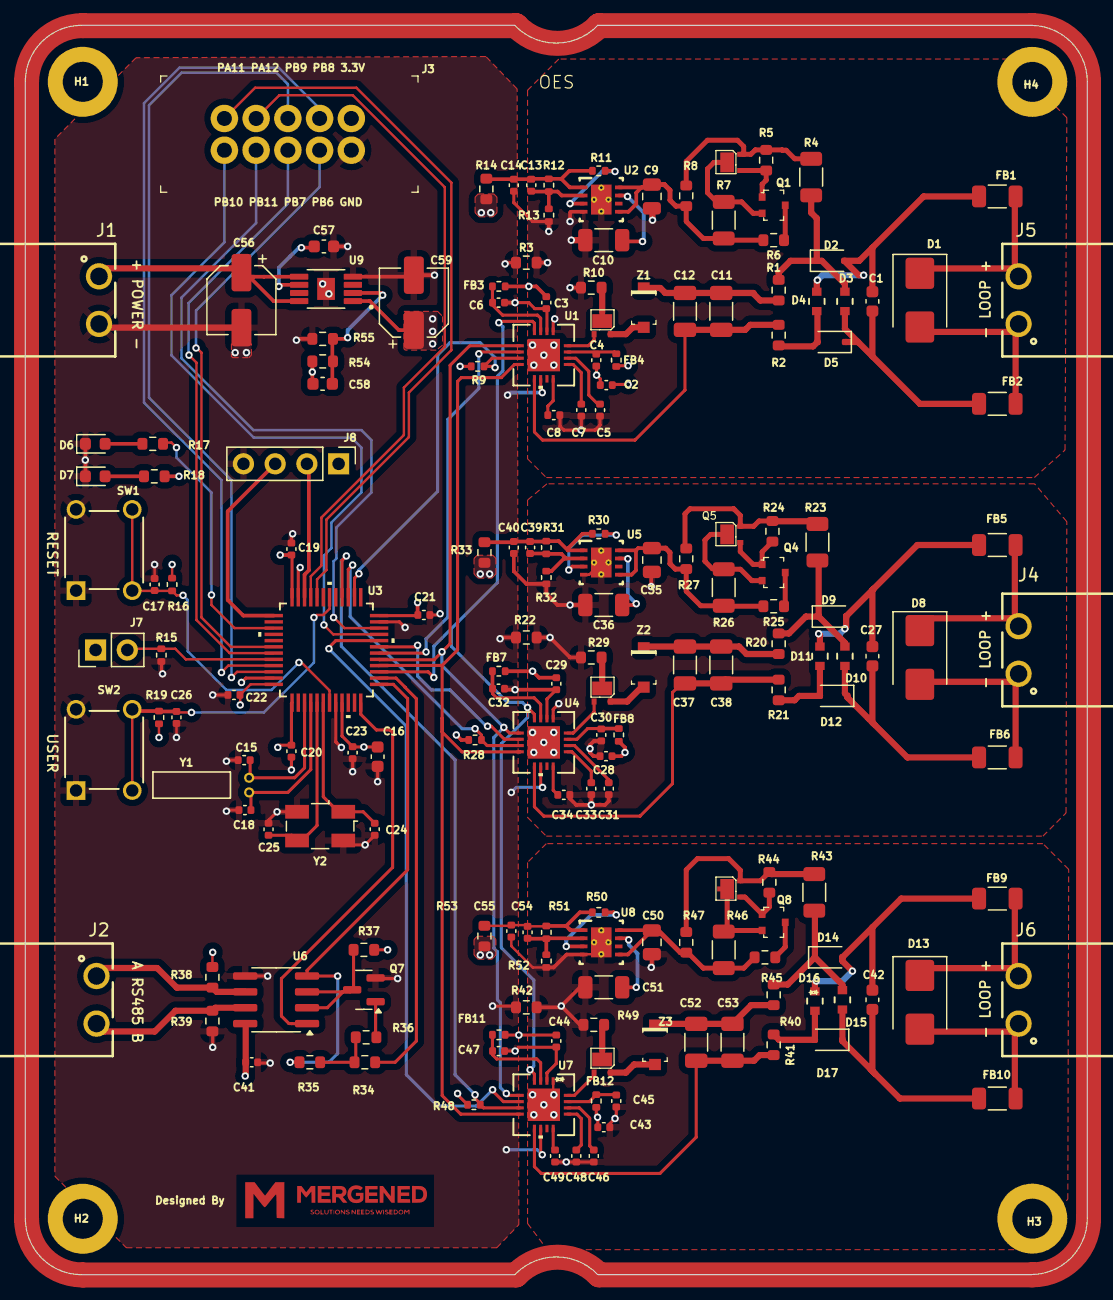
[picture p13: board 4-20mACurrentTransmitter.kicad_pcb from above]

Board: 4 copper layers, 85.0 x 100.0 mm, 181 parts (0 on the bottom side), 123 nets.
